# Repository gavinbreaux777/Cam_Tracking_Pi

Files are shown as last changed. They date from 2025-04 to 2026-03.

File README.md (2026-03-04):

# Cam\_Tracking\_Pi

Raspberry Pi version

&nbsp;		Overview: This project aims at creating a motion detecting/tracking/firing system to terrorize an entitled and panther-looking cat named Mitski. The system consists mechanically of a tilt/pan table mounted launching system that fires 3/4 inch foam balls that Mitski can't resist. The tilt/pan table is driven via 2 Nema 17 stepper motors, the launching mechanism is powered via 2 hobby dc 130 motors in a spinning-barrel style firing mechanism. The motion detection/tracking is accomplished via a Raspberry Pi Cam which leads me to - the brains of the operation lie in a Raspberry Pi 4B SBC that hosts a GUI using Flask, drives the motors, runs the camera, and controls the process. The main software components include the web-based GUI hosted by the Pi utilizing Flask, the code to control the camera and image processing, and the motor control. One more component to mention is the custom PCB design made and iterated here to include 3 voltage supply levels for logic and motor voltage.

&nbsp;		So far this repo includes several mechanical and software iterations. CAD files have not been tracked via git and are instead stored and versioned in a local file storage system. Images are included in the Images folder

&nbsp;	This project began back in 2023 in the midst of my first post-college job and my initial attempt was using an ESP32 microcontroller based system with the goal of creating an extremely cheap system with minimal external libraries/resources see other repo, (Cam\_Tracking\_ESP). This proved to be difficult as I learned a lot and ultimately decided I needed a more powerful controller with a some amount of pre-built architecture. I then took a hiatus from this project and returned to it at the beginning of 2025 with a new architecture and plan that is this repo. Documentation/images are lacking in different areas as this wasn't originally intended to be shared but just a fun project

<p align="center">
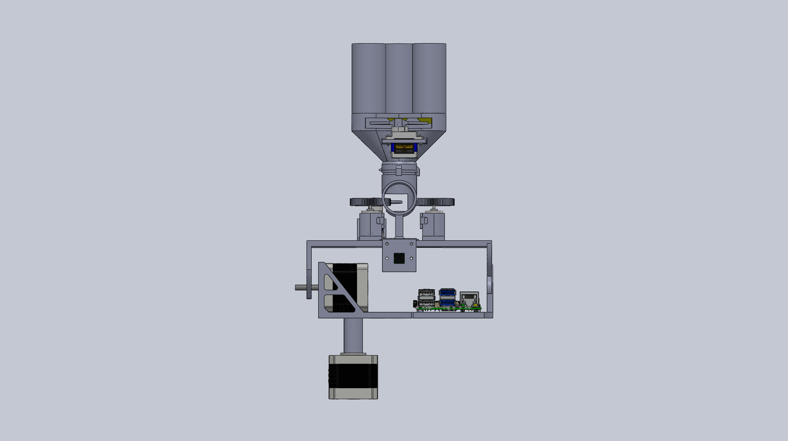
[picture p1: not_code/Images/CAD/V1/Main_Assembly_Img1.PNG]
System Image
  
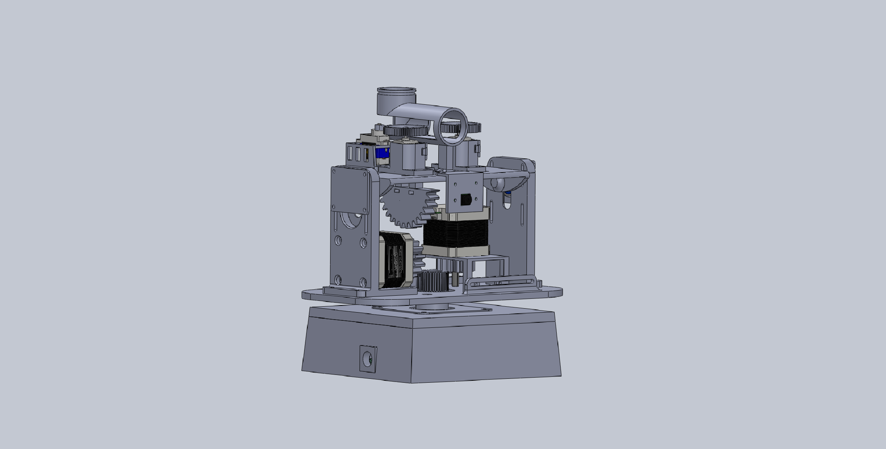
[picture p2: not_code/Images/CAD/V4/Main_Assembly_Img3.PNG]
System Image
  
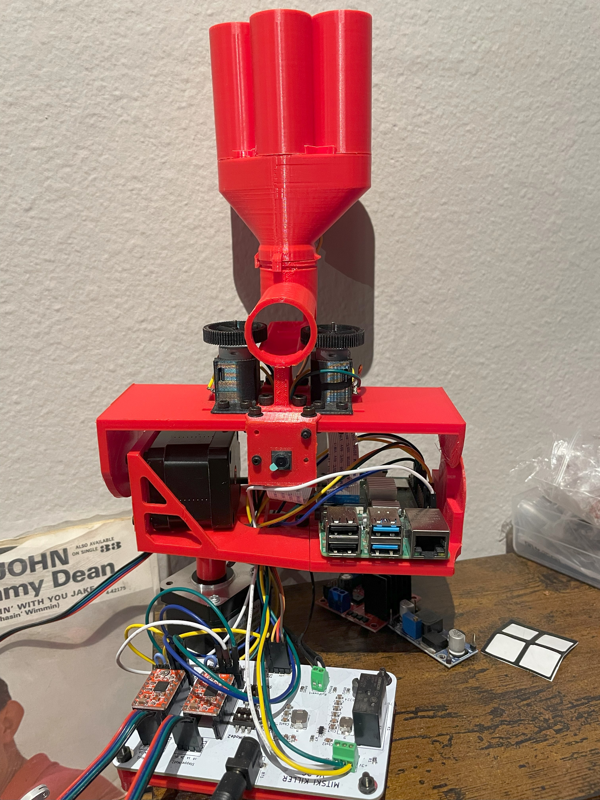
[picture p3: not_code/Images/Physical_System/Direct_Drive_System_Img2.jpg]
System Image
  
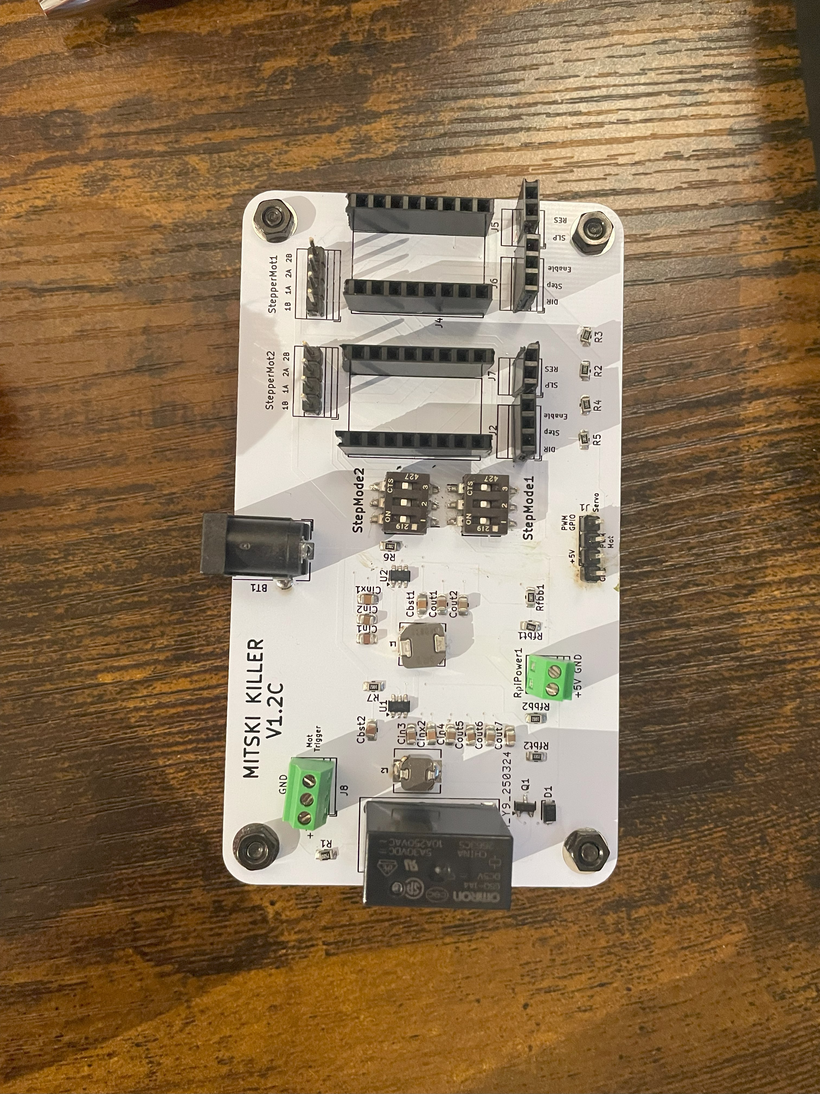
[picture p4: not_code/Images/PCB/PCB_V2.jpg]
System Image
  
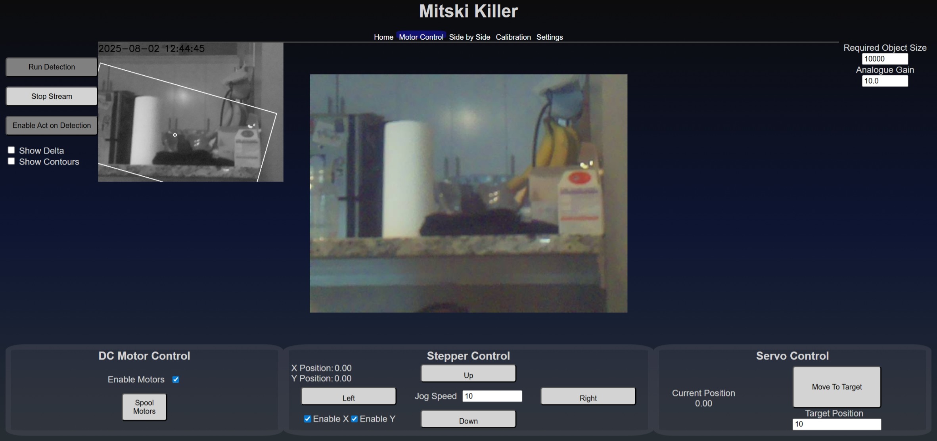
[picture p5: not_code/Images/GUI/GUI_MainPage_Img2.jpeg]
System Image
  
</p>

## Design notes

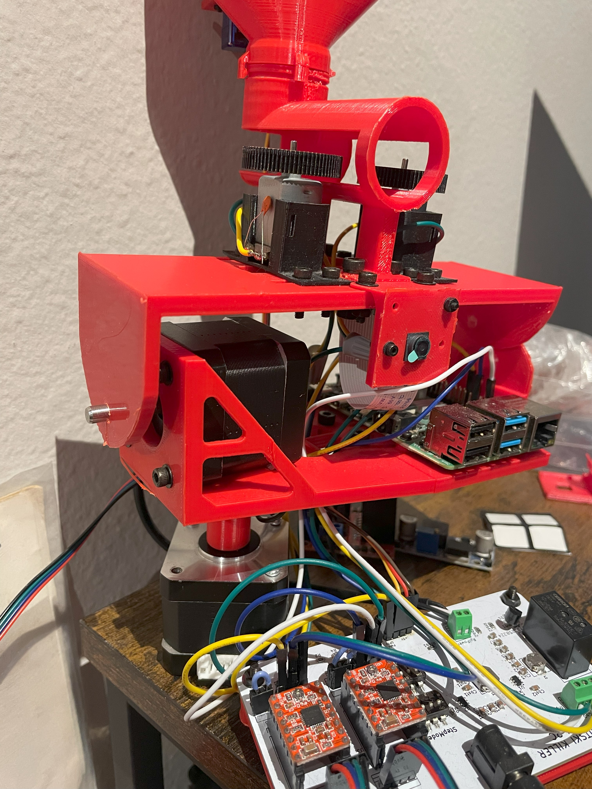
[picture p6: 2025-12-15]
not_code/Images/Physical_System/Direct_Drive_System_Img1.jpg

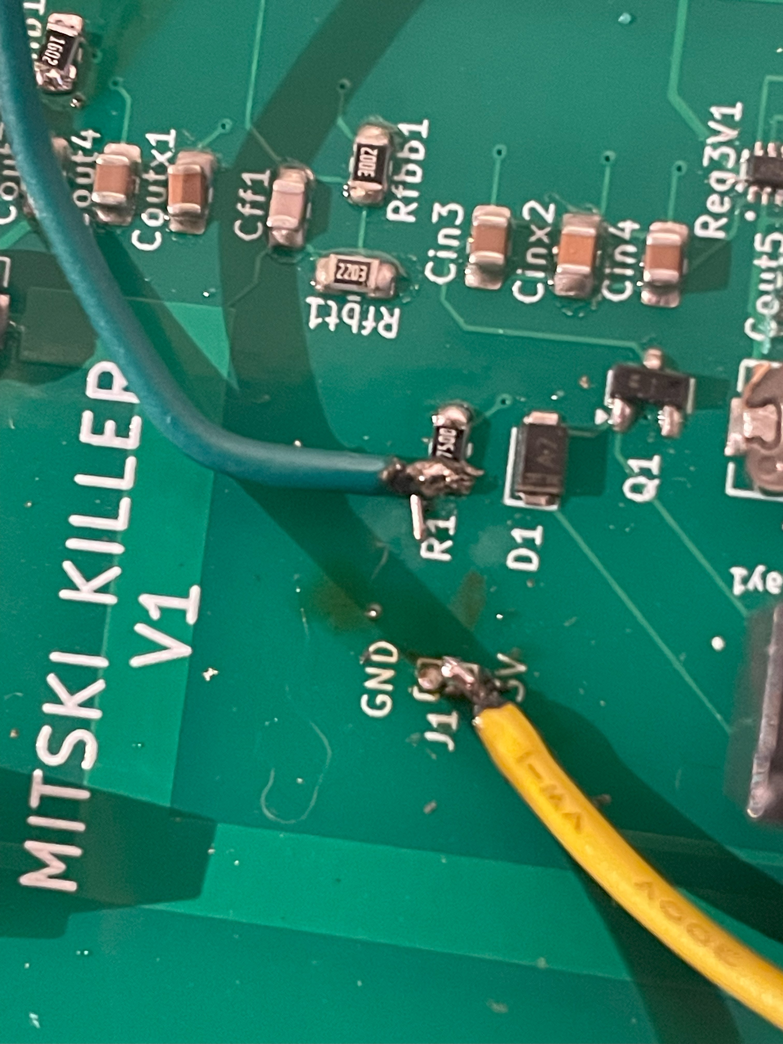
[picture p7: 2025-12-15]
not_code/Images/PCB/PCB_V1_Img2.jpg

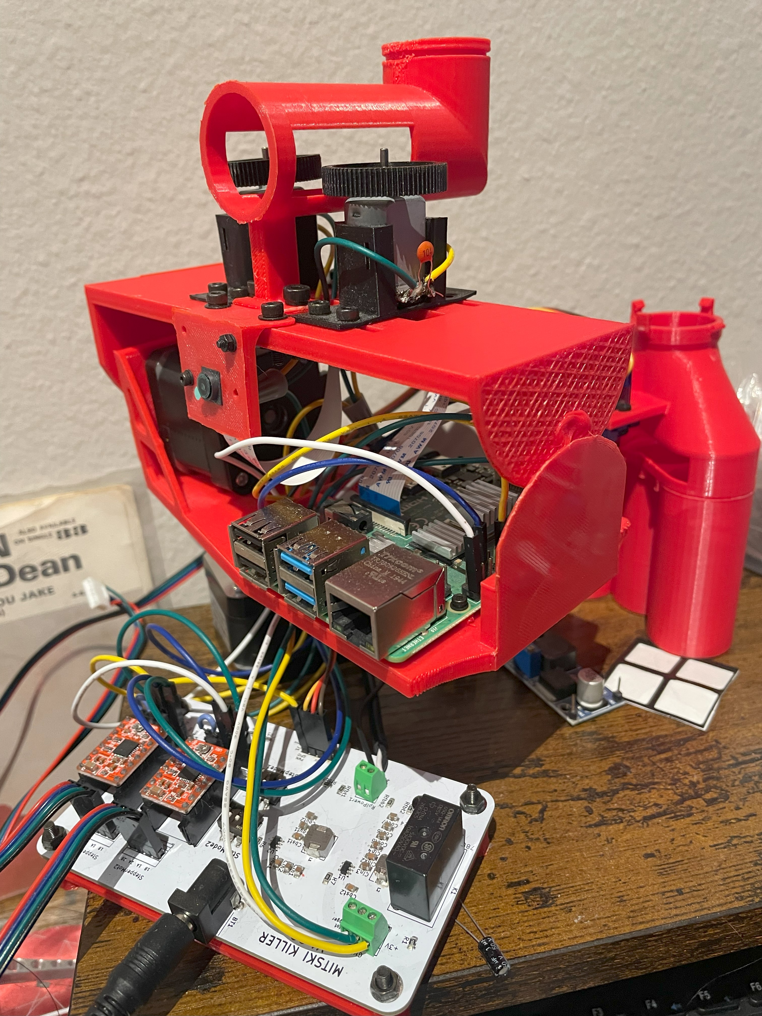
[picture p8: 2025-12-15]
not_code/Images/Physical_System/Direct_Drive_System_Img3.jpg

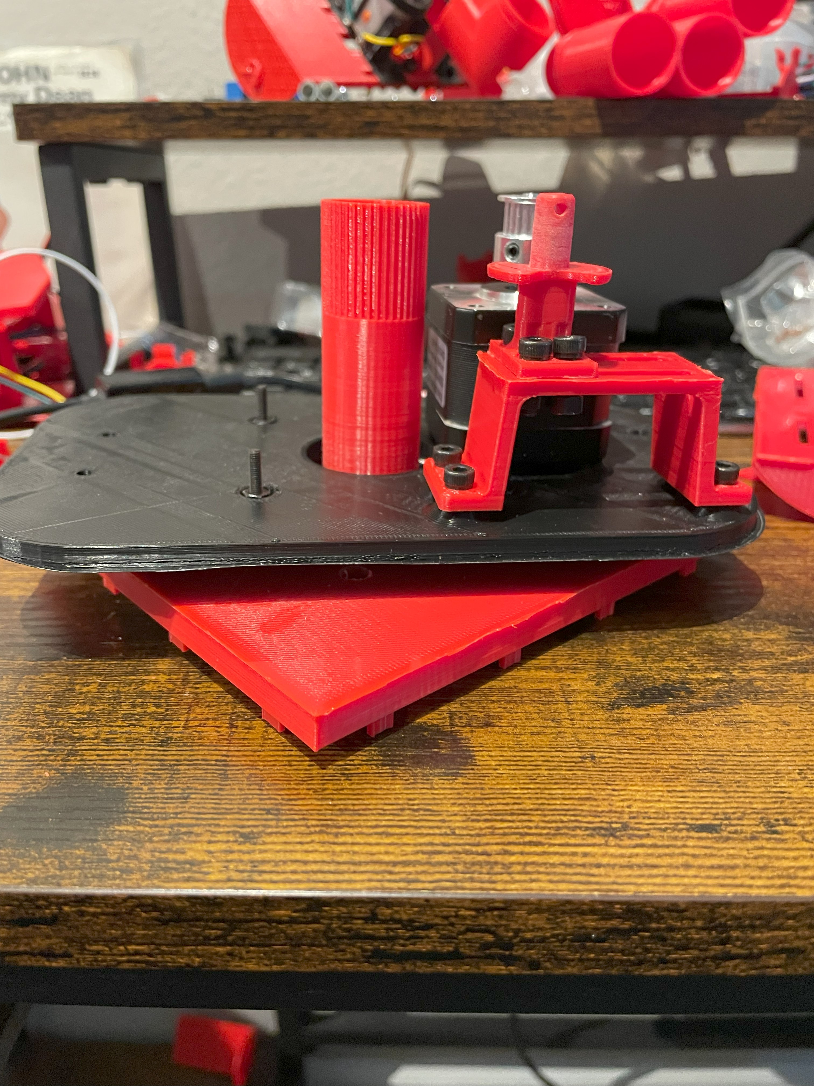
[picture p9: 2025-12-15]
not_code/Images/Physical_System/Belt_Driven_Pan_Table_Img2.jpg

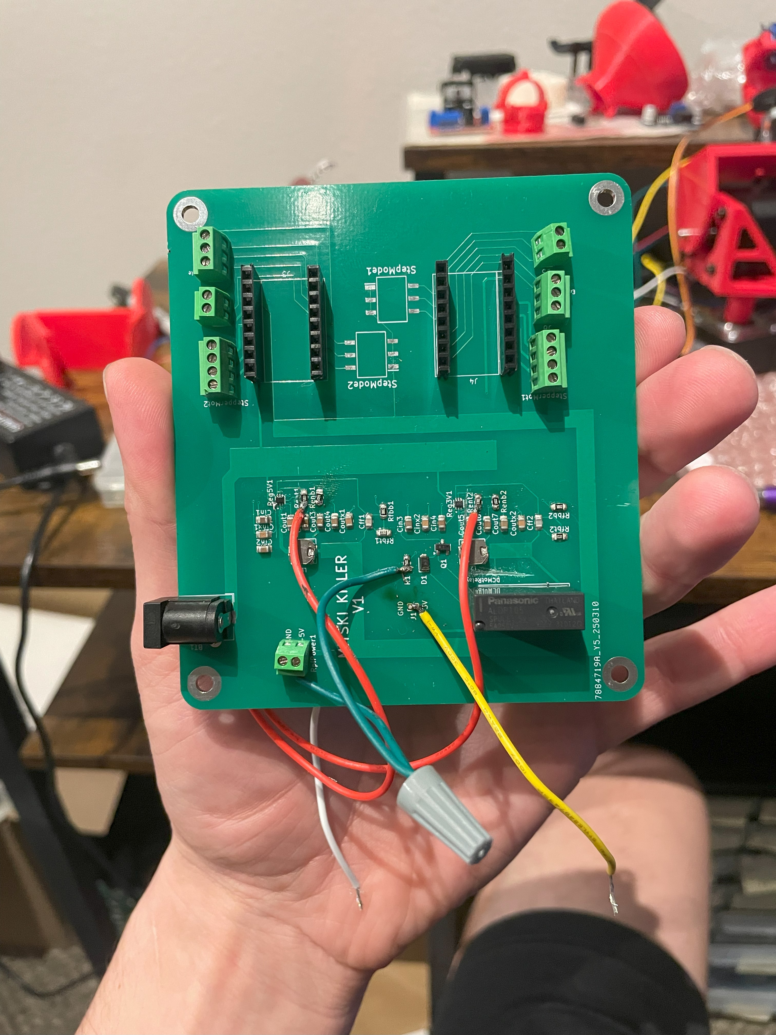
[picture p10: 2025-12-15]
not_code/Images/PCB/PCB_V1_Img1.jpg

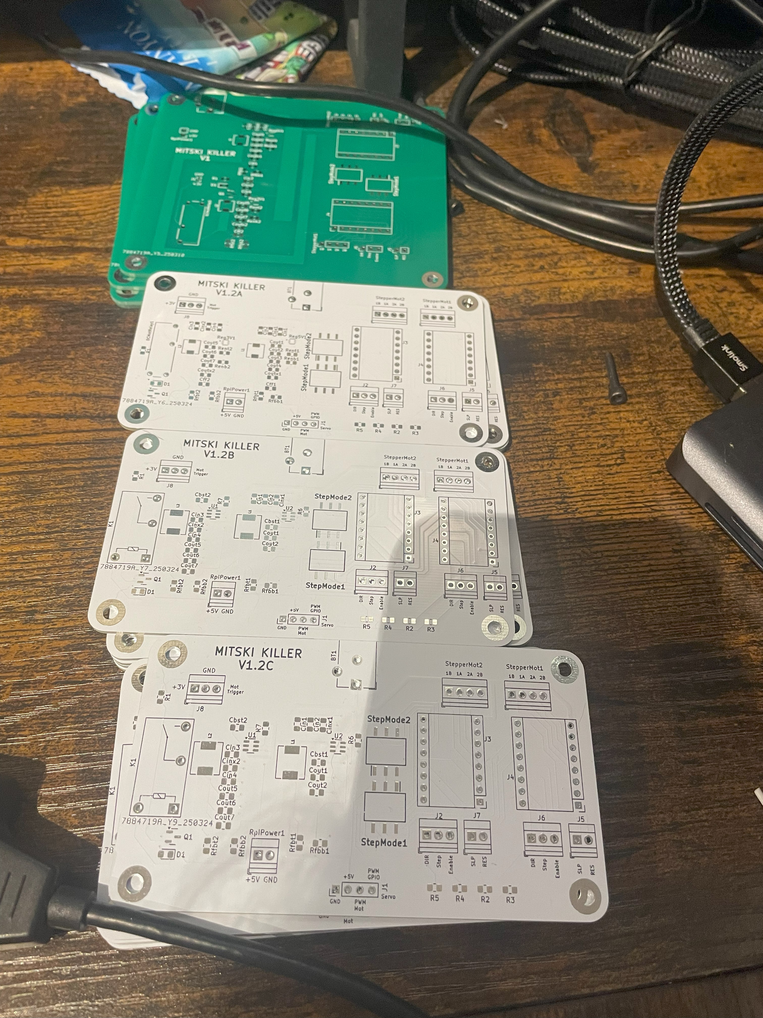
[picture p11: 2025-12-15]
not_code/Images/PCB/PCB_V1_and_V1.2A_B_C.jpg

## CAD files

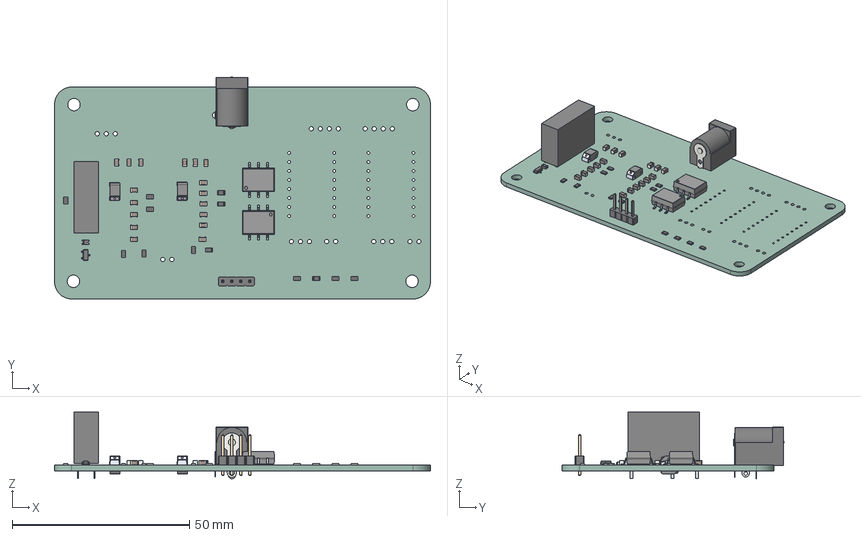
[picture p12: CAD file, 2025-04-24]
not_code/PCB/MitskiKiller/MitskiKillerV1_2A/MitskiKillerV1_2A.step
106.0 x 62.6 x 18.8 mm
C_0805_2012Metric x 17
R_0805_2012Metric x 13
BarrelJack_Horizontal
SPM5030T-4R7M-HZ x 2
PinHeader_1x04_P254mm_Vertical
ASSEMBLY x 2
D_0805
SOT_23
MitskiKillerV1_2A_PCB

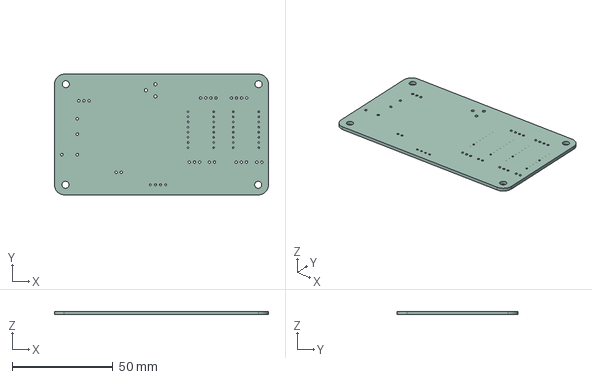
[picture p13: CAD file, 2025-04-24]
not_code/PCB/MitskiKiller/MitskiKillerV1_2B/MitskiKillerV1_2B.step
106.0 x 59.8 x 1.60 mm

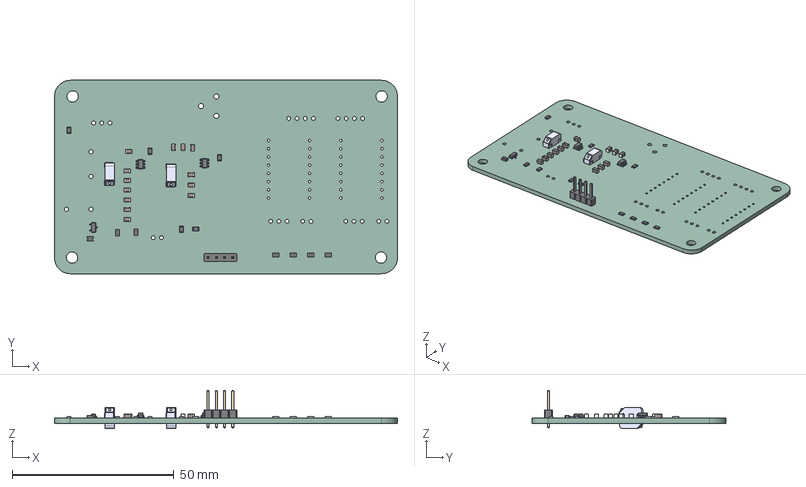
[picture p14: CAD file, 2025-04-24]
not_code/PCB/MitskiKiller/MitskiKillerV1_2C/MitskiKillerV1_2C.step
106.0 x 59.8 x 11.8 mm
R_0805_2012Metric x 11
C_0805_2012Metric x 13
SOT_23_6 x 2
SPM6530T-100M x 2
PinHeader_1x04_P254mm_Vertical
D_0805
SOT_23
_autosave-MitskiKillerV1_2C_PCB

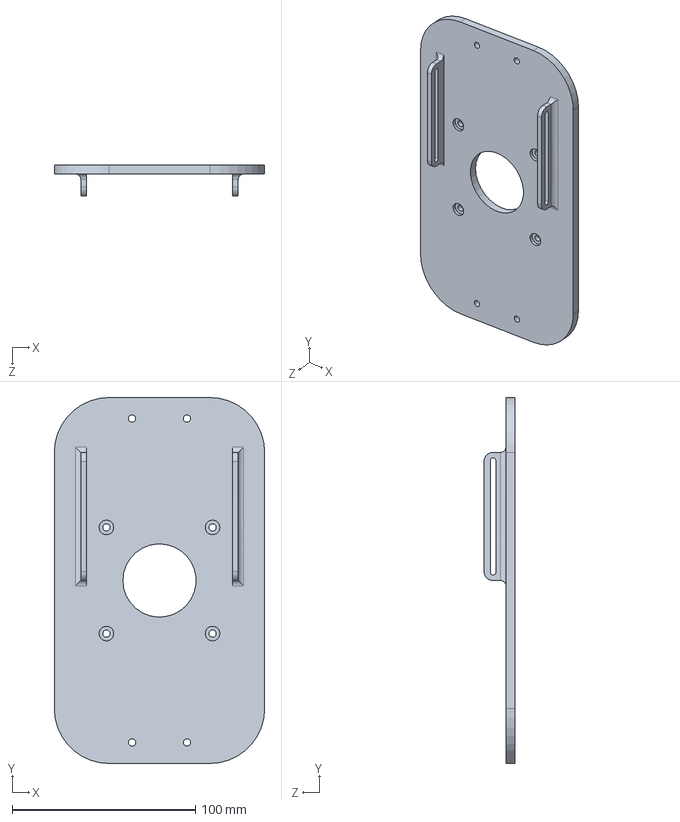
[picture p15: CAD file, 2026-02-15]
not_code/Solidworks/V4_Lazy Susan Top Plate_V4.SLDPRT
115.0 x 200.0 x 17.0 mm

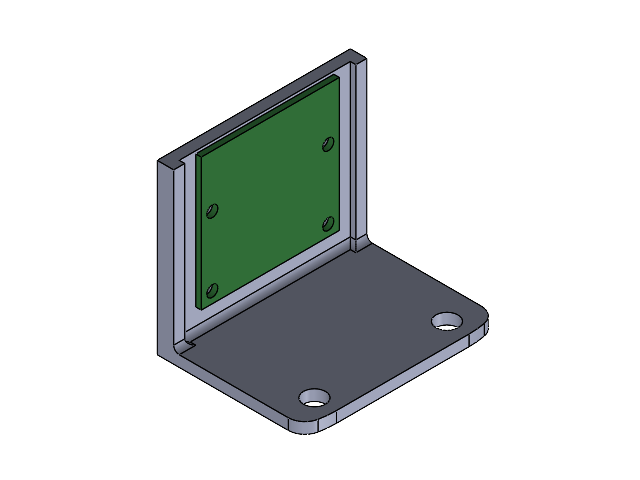
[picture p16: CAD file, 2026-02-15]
not_code/Solidworks/V4_Cam Case and Cam.SLDASM
V4_Cam case V4
V4_Raspberry Pi Camera

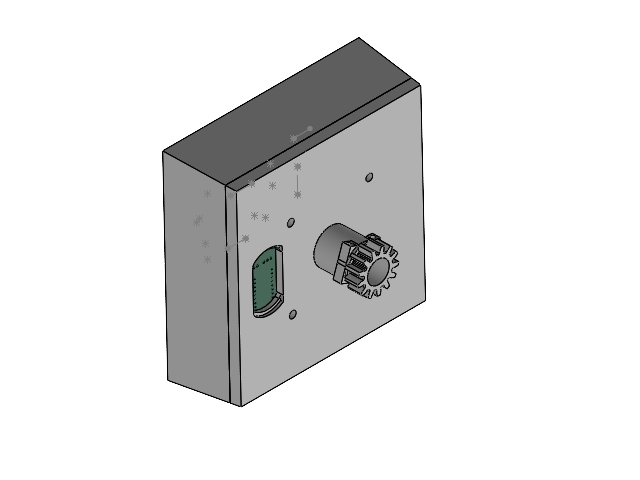
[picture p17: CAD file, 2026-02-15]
not_code/Solidworks/V4_Base_Assembly_V3.SLDASM
V4_PCB, RPi4ModelB
V4_Broadcom BCM2711B0 CPU, RPi4ModelB
V4_2.54 mm DUPONT MALE PIN HEADER, POE, 2X2, RPi4ModelB
V4_2.54 mm DUPONT MALE PIN HEADER, IO, 2X20, RPi4ModelB
V4_Camera Connector, RPi4ModelB
V4_Microphone Plug, RPi4ModelB
V4_Display Connector, RPi4ModelB
V4_Gigabit Ethernet Port, RPi4ModelB
V4_Female Micro HDMI Connector, RPi4ModelB x 2
V4_Female USB Type C Connector, RPi4ModelB
V4_2X USB3.0 PORTS, RPi4ModelB
V4_91D77 D9WHV 778K, 4 GB LPDDR4 SDRAM, RPi4ModelB
V4_Cypress CYW43455 Wireless Module Cover, RPi4ModelB
V4_SD Card Slot, RPi4ModelB
V4_VIA VL805 PCIe USB 3.0 controller, RPi4ModelB
V4_2X USB2.0 PORTS, RPi4ModelB
V4_Broadcom BCM54213PE Gigabit Ethernet Transceiver, RPi4ModelB
V4_MxL7704 Universal PMIC, RPi4ModelB
R_0805_2012Metric-0_1.step x 11
C_0805_2012Metric-1_1.step x 13
SOT_23_6_1.step x 2
SPM6530T-100M_1.step
PinHeader_1x04_P254mm_Vertical_1.step
D_0805_1.step
SPM6530T-100M-2_1.step
SOT_23_1.step
_autosave-MitskiKillerV1_2C_PCB_1.step
V4_Base_V4
V4_Y Motor Shaft Gear Parametric

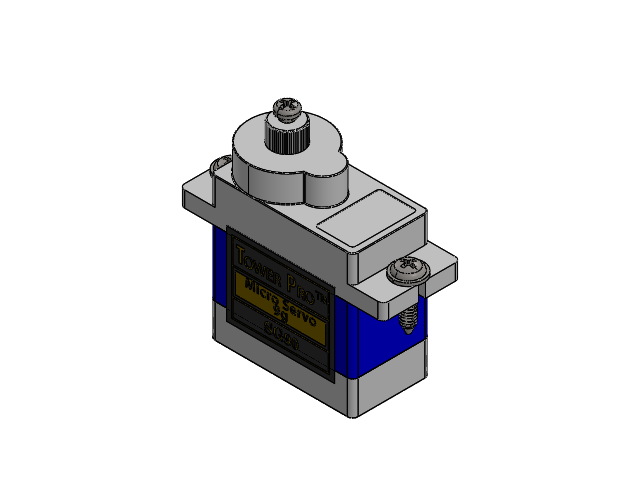
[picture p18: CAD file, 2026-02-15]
not_code/Solidworks/V4_SG90 - Micro Servo 9g - Tower Pro.SLDASM
SG90 - Micro Servo 9g - Tower Pro.1_Pe_a.STEP
SG90 - Micro Servo 9g - Tower Pro.5_BS EN ISO 7045 - M2 x 8 - Z - 8S.STEP x 2
SG90 - Micro Servo 9g - Tower Pro.6_BS EN ISO 7045 - M2 x 4 - Z - 4S.STEP

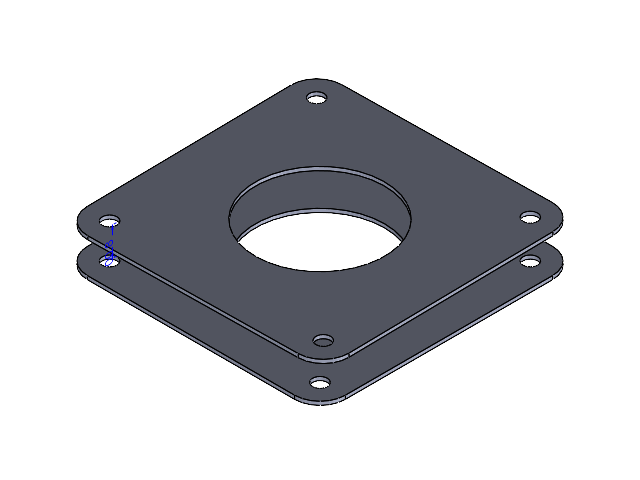
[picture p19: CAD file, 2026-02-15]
not_code/Solidworks/V4_Lazy Susan_V3.SLDASM
V4_Half Lazy Susan_V3 x 2

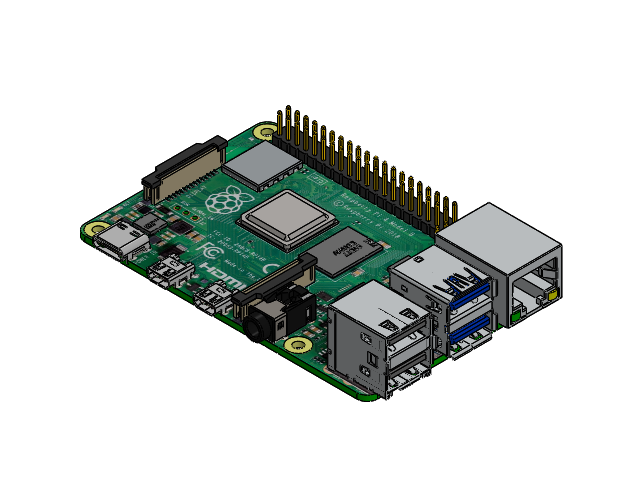
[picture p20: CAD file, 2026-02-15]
not_code/Solidworks/V4_Raspberry Pi 4 Model B.SLDASM
V4_PCB, RPi4ModelB
V4_Broadcom BCM2711B0 CPU, RPi4ModelB
V4_2.54 mm DUPONT MALE PIN HEADER, POE, 2X2, RPi4ModelB
V4_2.54 mm DUPONT MALE PIN HEADER, IO, 2X20, RPi4ModelB
V4_Camera Connector, RPi4ModelB
V4_Microphone Plug, RPi4ModelB
V4_Display Connector, RPi4ModelB
V4_Gigabit Ethernet Port, RPi4ModelB
V4_Female Micro HDMI Connector, RPi4ModelB x 2
V4_Female USB Type C Connector, RPi4ModelB
V4_2X USB3.0 PORTS, RPi4ModelB
V4_91D77 D9WHV 778K, 4 GB LPDDR4 SDRAM, RPi4ModelB
V4_Cypress CYW43455 Wireless Module Cover, RPi4ModelB
V4_SD Card Slot, RPi4ModelB
V4_VIA VL805 PCIe USB 3.0 controller, RPi4ModelB
V4_2X USB2.0 PORTS, RPi4ModelB
V4_Broadcom BCM54213PE Gigabit Ethernet Transceiver, RPi4ModelB
V4_MxL7704 Universal PMIC, RPi4ModelB

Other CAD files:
not_code/Solidworks/V4_Nema 17 Motor a Pasos 17HS4401_V3.SLDASM
not_code/Solidworks/V4_DC Motor Assembly.SLDASM
not_code/Solidworks/V4_Tilt Table Riser and Bearing Holder.SLDASM
not_code/Solidworks/V4_Motor-2_V3.SLDPRT
not_code/Solidworks/V4_Motor-24_V3.SLDPRT
not_code/Solidworks/V4_Motor-21_V3.SLDPRT
not_code/Solidworks/V4_Motor-10_V3.SLDPRT
not_code/Solidworks/V4_Motor-23_V3.SLDPRT
not_code/Solidworks/V4_Motor-15_V3.SLDPRT
not_code/Solidworks/V4 X Motor Upside Down Mount_1.SLDPRT
not_code/Solidworks/V4_2.54 mm DUPONT MALE PIN HEADER, IO, 2X20, RPi4ModelB.SLDPRT
not_code/Solidworks/V4_2.54 mm DUPONT MALE PIN HEADER, POE, 2X2, RPi4ModelB.SLDPRT
not_code/Solidworks/V4_2X USB2.0 PORTS, RPi4ModelB.SLDPRT
not_code/Solidworks/V4_2X USB3.0 PORTS, RPi4ModelB.SLDPRT
not_code/Solidworks/V4_3764N104_High-Strength Gt Timing Belt Pulley_V3.SLDPRT
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

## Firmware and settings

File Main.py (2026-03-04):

from ClassFactory import ClassFactory
from config.AppConfig import AppConfig

from FlaskServer import FlaskServer
from camera.Detector import Detector
from i_o.IOControl import IOControl

#load config values
config = AppConfig("config/")

#Create class to handle camera and image processing
picam2 = ClassFactory.ReturnCamera(config.cameraConfig)
detector = Detector(picam2, config.imageProcessorConfig)

#Create class to handle IO
io = ClassFactory.ReturnIO(config.ioConfig)
ioControl = IOControl(io)

#Create class to control all motors, aiming and projection
motorControl = ClassFactory.ReturnMotorControl(ioControl, config.motorConfig, config.systemConfig)

try:
    #code start
    
    #Start the camera recording
    detector.StartRecording()    
    
    #start Flask server with output from camera recording
    server = FlaskServer(detector, motorControl, config)

    detector.RegisterObserver(motorControl)
    detector.RegisterObserver(server)
    
    server.startServer()

finally:
    detector.StopRecording()

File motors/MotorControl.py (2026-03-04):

from .AimingControl import AimingControl
from helpers.Observer import DetectionObserver
from .MotorEnums import MotorEnum
from .FiringControl import FiringControl
from config.ConfigClasses import SystemConfig
import threading
from typing import Tuple, Callable
import time
class MotorControl(DetectionObserver):
    def __init__(self, aimingControl: AimingControl, firingControl: FiringControl, config: SystemConfig):
        self.aimingControl = aimingControl
        self.firingControl = firingControl
        self._config = config

#region universal commands
    def StopMotor(self, motorNum: MotorEnum):
        match motorNum:
            case MotorEnum.Pan | MotorEnum.Tilt:
                self.aimingControl.StopMotors()
            case MotorEnum.Spool:
                self.firingControl.StopMotors()
            case MotorEnum.Chamber:
                print("Stop not implemented for chamber servo")
            case _:
                print("Unknown motor")
        
    def MoveMotorRel(self, motorNum: MotorEnum, target: float):
        match motorNum:
            case MotorEnum.Pan:
                self.aimingControl.MoveXRel(target)
            case MotorEnum.Tilt:
                self.aimingControl.MoveYRel(target)
            case MotorEnum.Spool:
                print("Unable to move dc motor to target. Use Spool command instead")
            case MotorEnum.Chamber:
                print("Relative move not implemented for servos. Use absolute move")
            case _:
                print("Unknown motor")

    def MoveMotorAbs(self, motorNum: MotorEnum, target: float):
        match motorNum:
            case MotorEnum.Pan:
                self.aimingControl.MovePanAbs(target)
            case MotorEnum.Tilt:
                self.aimingControl.MoveTiltAbs(target)
            case MotorEnum.Spool:
                print("Unable to move dc motor to target. Use Spool command instead")
            case MotorEnum.Chamber:
                self.firingControl.SetChamberServoAngle(target)
            case _:
                print("Unknown motor")

    def JogMotor(self, motorNum: MotorEnum, speed: int, direction: bool):
        match motorNum:
            case MotorEnum.Pan:
                self.aimingControl.Jog(speed, direction, MotorEnum.Pan)
            case MotorEnum.Tilt:
                self.aimingControl.Jog(speed, direction, MotorEnum.Tilt)
            case MotorEnum.Spool:
                print("Unable to jog dc motor. Use Spool command instead")
            case MotorEnum.Chamber:
                print("Jog not implemented for chamber servo")
            case _:
                print("Unknown motor")
    
    def EnableMotor(self, motorNum: MotorEnum):
        match motorNum:
            case MotorEnum.Pan | MotorEnum.Tilt:
                self.aimingControl.EnableMotor(motorNum)
            case MotorEnum.Spool | MotorEnum.Chamber:
                self.firingControl.EnableMotor(MotorEnum.Spool)
            case _:
                print("Unknown motor")

    def DisableMotor(self, motorNum: MotorEnum):
        match motorNum:
            case MotorEnum.Pan | MotorEnum.Tilt:
                self.aimingControl.DisableMotor(motorNum)
            case MotorEnum.Spool | MotorEnum.Chamber:
                self.firingControl.DisableMotor(motorNum)
            case _:
                print("Unknown motor")

    def GetMotorPos(self, motorNum: MotorEnum) -> float:
        match motorNum:
            case MotorEnum.Pan | MotorEnum.Tilt:
                return self.aimingControl.motorPositions[motorNum]
            case MotorEnum.Spool:
                print("Invalid request: Unable to get position of dc motor")
            case MotorEnum.Chamber:
                return self.firingControl.motorPositions[motorNum]
            case _:
                print("Unknown motor")
#endregion


#region aimingControl commands
    def AimPanTiltRel(self, xDegrees: float, yDegrees: float):
        self.aimingControl.AimPanTiltRel(xDegrees, yDegrees)

    def OnMotionFound(self, location, acknowledgeCallback):
        '''Start thread to handle firing so image generation/processing can continue'''
        print("Motor control notified. Act on detection = " + str(self._config.actOnDetection))
        if(self._config.actOnDetection== True):
            print("starting motion thread")
            searchAndDestroyThread = threading.Thread(target=lambda: self.FindAndFire(location, acknowledgeCallback))
            searchAndDestroyThread.start()
            searchAndDestroyThread.join()

        #Notify detector that firing sequence is complete
        acknowledgeCallback(True)

    def FindAndFire(self, location: Tuple[int, int], callback: Callable[[bool], None]):
        '''Aim motors, fire projectile, and finally call callback to notify Detector that we've finished the sequence'''
        #detector give location in terms of offset from center of camera frame, based on camera resolution
        #convert from these pixel offsets to motor movements
        print("running find and fire")
        self.firingControl.SpoolMotors()

        xAdjustment, yAdjustment = self.CalculateMotorAdjustments(location)   
        print("aiming motors: " + str(xAdjustment) + " degrees x, " + str(yAdjustment) + " degrees y")
        self.AimPanTiltRel(xAdjustment, yAdjustment)
        print("Motors aimed, waiting for spool")
        while(not self.firingControl.motorsSpooled):
            pass
        print("Motors spooled, firing chamber servo")
        self.firingControl.ChamberSingle()
        time.sleep(0.5)
        self.firingControl.StopMotors()
    
    def CalculateMotorAdjustments(self, percentFromCenter: Tuple[int, int]) -> Tuple[float, float]:
        '''Convert from pixel offset-from-center of camera frame to motor degrees'''

        #Motor travel distance in degrees
        xAdjustment = percentFromCenter[0] * self._config.panDegreesPerCamPercentChange
        yAdjustment = -1 * percentFromCenter[1] * self._config.tiltDegreesPerCamPercentChange
        return xAdjustment, yAdjustment

    def SetTiltLimits(self, limits: Tuple[float, float]):
        """
        Set CW and CCW limits for tilt motor in degrees

        Args:
            limits: position limits in degrees (CW limit, CCW limit)
        """
        self.aimingControl.SetTiltMotorLimits(limits)

    def SetTiltLimit(self, limit: float, isUpper: bool):
        """
        Set either upper or lower limit for tilt motor in degrees

        Args:
            limit: position limit in degrees
            isUpper: true if setting upper limit, false if setting lower limit
        """
        self.aimingControl.SetTiltMotorLimit(limit, isUpper)

    def GetTiltLimits(self) -> Tuple[float, float]:
        '''Returns tilt motor limits in degrees (cw limit, ccw limit)'''
        return self.aimingControl.GetTiltLimits()
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

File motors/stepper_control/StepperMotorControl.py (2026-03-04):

from fractions import Fraction
import concurrent.futures 
import threading

from typing import Tuple
from .StepperMotorControlInterface import StepperMotorControlInterface
from .RawStepperControl import RawStepperControl
from i_o.IOControl import IOControl
from config.ConfigClasses import SingleAimMotorConfig
from .Limits import Limits

class StepperMotorControl(StepperMotorControlInterface):
    '''
    Higher level stepper control class that deals in real-world units.
    Does not deal directly with io
    '''
    def __init__(self, ioControl: IOControl, config: SingleAimMotorConfig):
        self.motor = RawStepperControl(ioControl, config.stepPin, config.dirPin, config.enablePin, config.stepMode, config.stepsPerRev)
        self.timeout = 10 #setting really high right now because we're not using rn. (client *should resend jog command before shorter timeout but currently only sending 1 start and 1 stop command from client)
        self._jogTimer = threading.Timer(self.timeout, self.StopMotors)
        self._hasBeenHomed = False
        self._limits = Limits()
        self._config = config

    @property
    def hasBeenHomed(self) -> bool:
        '''True if home reference point has been set since startup'''
        return self._hasBeenHomed

    @property
    def limits(self) -> tuple[float, float]:
        '''Position limits in degrees (lower, upper)'''
        return (self._limits.lower, self._limits.upper)

    @property
    def enabled(self) -> bool:
        return self.motor.enabled
    @enabled.setter
    def enabled(self, value: bool):
        self.motor.enabled = value

    @property
    def position(self) -> float:
        '''In degrees'''
        return self.ConvertStepsToDegrees(self.motor.position)
    @position.setter
    def position(self, value: float):
        self.motor.position = value  
        
    @property
    def _stepsPerRevoluton(self):
        ''''''
        return self._config.stepsPerRev / self._config.stepMode

    @property
    def _stepsPerDegree(self):
        return self._config.stepsPerRev / 360 
    
    @property
    def speed(self) -> float:
        '''speed of motor rotation in degrees/sec (actual speed ~15% slower than commanded per initial tests)'''
        return self._speed
    
    @speed.setter
    def speed(self, degPerSec):
        print("Setting speed in StepeprMotorControl")
        self._speed = degPerSec

    @property
    def _delayBetweenSteps(self):
        '''Time in seconds between consecutive step pulses'''
        return self.CalculateDelayBetweenSteps(self._config.speed)
    
    @property
    def accel(self, degreesPerSecondSquared: float):
        '''Currently not in use'''
        pass

    def CalculateDelayBetweenSteps(self, speedIn_ms):
        return 1 / speedIn_ms / (self._stepsPerDegree)

    def ConvertDegreesToSteps(self, degrees: float) -> int:
        return int(degrees * self._stepsPerDegree)
    
    def ConvertStepsToDegrees(self, steps: int) -> float:
        return float(steps / self._stepsPerDegree)

    def RotateRel(self, degrees: float) -> bool:
        """
        Rotate motor relative to current position
        Args:
            degrees: degrees to rotate (positive is clockwise)

        returns: true if made position, false if not
        """
        if(degrees < 0):
            cw = False
        else: 
            cw = True
        stepsToTake = abs(self.ConvertDegreesToSteps(degrees))

        madePosition = self.motor.MotorRotate(cw, stepsToTake, self._delayBetweenSteps)
        return madePosition

    def RotateAbs(self, targetDegrees: float):
        """
        Rotate motor to absolute position in degrees
        Args:
            degrees: degrees target

        returns: true if made position, false if not
        """
        degreeChange = targetDegrees - self.position
        if(degreeChange < 0):
            cw = False
        else:
            cw = True            
        stepsToTake = abs(self.ConvertDegreesToSteps(degreeChange))

        madePosition = self.motor.MotorRotate(cw, stepsToTake, self._delayBetweenSteps)
        return madePosition

    def Stop(self):
        self.motor.StopMotor()

    def Jog(self, speed: int, cw: bool):
        "Start motor moving clockwise at specified speed"
        stepsToTake = 10000
        delayBetweenSteps = self.CalculateDelayBetweenSteps(speed)
        #Start a thread so the function can return immediately, but start a timer to stop motors if timeout met
        threadPool = concurrent.futures.ThreadPoolExecutor()
        threadPool.submit(self.motor.MotorRotate(cw, stepsToTake, delayBetweenSteps))
        self.RestartJogTimer()

    def RestartJogTimer(self):
        '''Cancels current timeout timer if active and starts a new one for the timeout duration'''
        self._jogTimer.cancel()
        self._jogTimer = threading.Timer(self.timeout, self.StopMotors)
        self._jogTimer.start()

    def StopMotors(self):
        self.Stop()
        self._jogTimer.cancel()

    def SetLimit(self, limit: float, isUpper: bool):
        '''
        Set either upper or lower limit in degrees
        
        Args:
            limit: position limit in degrees
            isUpper: true if setting upper limit, false if setting lower limit
        '''        
        stepLimit = self.ConvertDegreesToSteps(limit)
        print("Converted stepLimit = " + str(stepLimit))
        self.motor.SetLimit(stepLimit, isUpper)
        if isUpper:
            self._limits.upper = limit
        else:
            self._limits.lower = limit

    def SetLimits(self, limits: Tuple[float, float]):
        '''
        Set lower and upper limits in degrees
        
        Args:
            limits: position limits in degrees (lower, upper)
        '''
        print("Shouldnt be here")
        cwStepLimit = self.ConvertDegreesToSteps(limits[0])
        ccwStepLimit = self.ConvertDegreesToSteps(limits[1])
        
        self.motor.SetLimits((cwStepLimit, ccwStepLimit))
        self._limits.lower = limits[0]
        self._limits.upper = limits[1]

    def SetHomeReference(self):
        '''Set current position of motor as home reference point (0 degrees)'''
        self.motor.SetHomeReference()
        self._hasBeenHomed = True

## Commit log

2025-01-25 Reorganized, created motor control class
2025-01-26 Created basic motor control class
2025-02-01 Added React functionality and button grid
2025-02-18 Added observerver pattern for motorControl-Detector notification, initial use of FiringControl class and added to ProcessImage method,
2025-02-27 Added xy motor calibration function/route from webpage to server
2025-03-01 Added servo control, created own stepper library to allow position tracking, added handling for different step modes, fixed logic for detection location - motor movement
    [AimingControl.py, Detector.py, FiringControl.py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]
2025-03-02 Added manual servo control, refactored javascript
2025-03-09 PCB Version 1
    [DCMotors.kicad_sch, PwrReg3Volt.kicad_sch, PwrReg5Volt.kicad_sch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]
2025-03-12 Switched to pigpio library
2025-03-13 Added ability to disable steppers from gui, added option to show delta or contoured image, (biggest one) - made webpage background GRAY
2025-03-17 PCB design updates
    [3VMotors.kicad_sch, 5VMotors.kicad_sch, PwrReg3Volt.kicad_sch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]
2025-03-22 PCB reorganization after testing, moved pcb file location
    [3VMotors.kicad_sch, 5VMotors.kicad_sch, DCMotors.kicad_sch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]
2025-03-22 Created pcb v1.2 - fixes from testing of v1.1
    [3VMotors.kicad_sch, 5VMotors.kicad_sch, DCMotors.kicad_sch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]
2025-03-23 Added version B of version 1.2 pcb, modified components on board such as relays and voltage converters
    [3VMotors.kicad_sch, 5VMotors.kicad_sch, DCMotors.kicad_sch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]
2025-03-23 Created PCB version 1.2C
    [3VMotors.kicad_sch, 5VMotors.kicad_sch, DCMotors.kicad_sch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]
2025-04-23 Added manual dc motor control and option to not act on detection
2025-04-24 Added pcb step files
    [MitskiKillerV1_2A.step, MitskiKillerV1_2B.step, MitskiKillerV1_2C.kicad_pcb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]
2025-04-27 Bug fixes and cleanup
    [Detector.py, MotorControl.py]
2025-04-28 Added calibration data
2025-04-28 Minor layout fixes, added stepper position readout
    [AimingControl.py, FiringControl.py, MotorControl.py]
2025-05-04 Added 3 part ammo inlet and refactored FiringControl into DCMotorControl and ServoControl
2025-05-25 Small fixes to get webpage working again
    [FlaskServer.py, MotorControl.py, ServoControl.py]
2025-06-09 Added separate control for chamber servo and ammo servo
2026-01-17 1-added buttons to train chamber servo open/closed and move to these positions
2026-01-18 Ref #26 Add test framework and a few basic server tests
2026-01-26 Some config classes put together and loading from json
    [MotorsConfig.json]
2026-01-26 Added tests to verify config fields have values and general fixes
    [MotorsConfig.json]
2026-01-26 Organized css a bit, got calibration crosshair working better
2026-01-26 Changed alignment end of calibration button/image stack
2026-02-04 updated motor control architecture and added tests for each endpoint
    [MotorsConfig.json]
2026-02-07 testing fixes, moved some flask endpoints to separate files using flask blueprints
    [AimingControl.py, Detector.py, FlaskServer.py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]
2026-02-07 39 removed old route from tests and self reference from motors route
2026-02-07 organized files
    [3VMotors.kicad_sch, 5VMotors.kicad_sch, DCMotors.kicad_sch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]
2026-02-08 33 add homing for tilt axis (#58)
    * 33 add manual home reference set for tilt axis (no home sensor)
    * 33-bug fixes
    [AimingControl.py, ClassFactory.py, Detector.py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]
2026-02-15 add solidworks files using git lfs (#59)
    [V4 X Motor Upside Down Mount_1.SLDPRT, V4_2.54 mm DUPONT MALE PIN HEADER, IO, 2X20, RPi4ModelB.SLDPRT, V4_2.54 mm DUPONT MALE PIN HEADER, POE, 2X2, RPi4ModelB.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]
2026-03-04 Testing branch (#67)
    * Update README.md
    updated image location references
    * fixes from testing, added pan/tilt setting
    * fixed obj required size config writing
    * Corrected pan jog directions
    [MotorsConfig.json]
